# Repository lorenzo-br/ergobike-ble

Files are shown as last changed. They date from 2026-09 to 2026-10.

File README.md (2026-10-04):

# 🚴 ErgoBike BLE - Adaptador Bluetooth Smart para Bike Ergométrica

<p align="center">
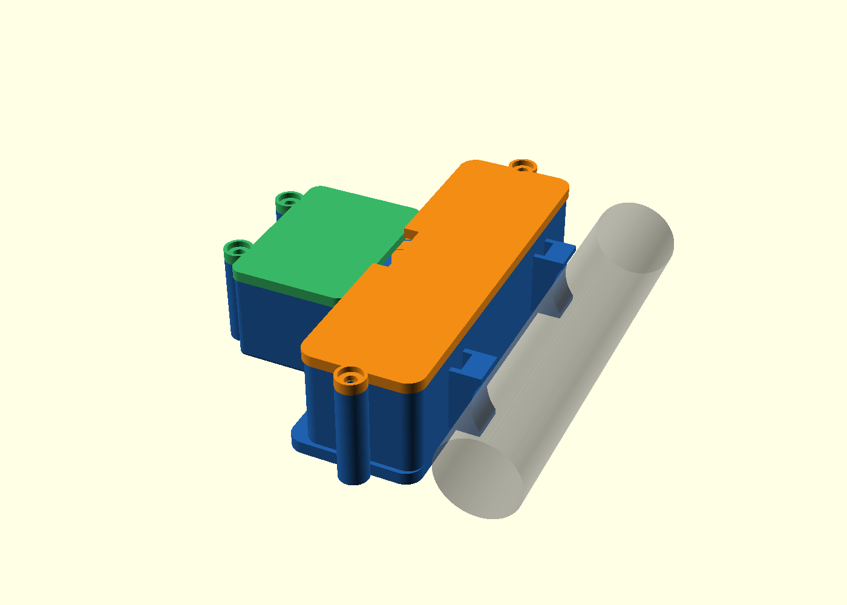
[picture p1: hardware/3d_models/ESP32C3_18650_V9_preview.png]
ErgoBike BLE 3D Enclosure
  
</p>

<p align="center">
  
  
  
  
  
</p>

---

Transforme sua bicicleta ergométrica convencional com medidor de pulso simples (cabo P1/P2) em um **Smart Indoor Trainer Bluetooth** completo e de alta precisão, compatível nativamente com o **CycleGo**, **Zwift**, **MyWhoosh**, **Kinomap**, **Wahoo Fitness**, **Rouvy**, **Strava** e outros aplicativos de treino indoor.

Desenvolvido para **ESP32-C3** (RISC-V) alimentado por uma bateria **18650**, com consumo ultra-baixo em repouso (**Deep Sleep < 15 µA**), despertar automático ao primeiro giro do pedal e um **Portal Wi-Fi de Auto-Calibração** sem necessidade de abrir a carenagem da bike.

---

## 🌟 Principais Recursos

- **Dual-Stack BLE Oficial (CSCS + FTMS + BAS):**
  - **CSCS (Cycling Speed and Cadence Service - `0x1816`):** Padrão universal para cadência e velocidade com base de tempo de 1/1024s, SC Control Point (`0x2A55`) e localização do sensor.
  - **FTMS (Fitness Machine Service - `0x1826`):** Padrão moderno de *Indoor Bike Data* (`0x2AD2`) com velocidade, cadência, potência estimada (Watts), Status (`0x2ADA`) e Control Point (`0x2AD9`).
  - **Battery Service (`0x180F`):** Monitoramento contínuo da porcentagem da célula 18650 diretamente no app.
- **Assistente de Auto-Calibração (10 Voltas no Pedal):**
  - Calibração guiada via navegador: dê 10 voltas no pedal e o sistema calcula a relação de polia da roda de inércia automaticamente.
- **Gestão Inteligente de Energia (Deep Sleep):**
  - Desliga automaticamente após 3 minutos de inatividade.
  - Desperta instantaneamente no primeiro pulso do ímã (GPIO 21 interrupt wake).
- **Portal Web Wi-Fi Responsivo + Atualização OTA:**
  - Dashboard ao vivo com velocímetro, cadência e nível de bateria.
  - Atualização de firmware sem fios (Over-The-Air) pelo celular ou notebook.
- **Enclosure 3D V9 Sob Medida:**
  - Compartimento dedicado para ESP32-C3 + suporte para bateria 18650 com tampas parafusadas e abraçadeira para tubo de 20 mm.

---

## 📱 Compatibilidade de Aplicativos

| Aplicativo | Protocolo BLE Utilizado | Métricas Suportadas |
| :--- | :--- | :--- |
| **CycleGo** | CSCS / FTMS | Cadência (RPM) e Velocidade (km/h) |
| **Zwift** | FTMS / CSCS | Cadência, Velocidade, Potência Estimada e Bateria |
| **MyWhoosh** | FTMS / CSCS | Cadência, Velocidade e Potência Estimada |
| **Kinomap** | FTMS / CSCS | Cadência, Velocidade e Potência Estimada |
| **Wahoo Fitness** | CSCS | Cadência, Velocidade e Bateria |
| **Rouvy** | CSCS | Cadência e Velocidade Virtual |
| **Strava** (Gravação) | CSCS | Cadência e Velocidade do Treino |
| **nRF Connect** | CSCS + FTMS + BAS + DIS | Diagnóstico completo de GATT |

---

## 🛠️ Esquema Elétrico e Conexões

### Opção A: Placa de Expansão ESP32-C3 SuperMini (AliExpress) — *Recomendado*

A placa de expansão para ESP32-C3 SuperMini simplifica a montagem física:
- **Porta de Bateria PH2.0 integrada:** basta plugar a bateria 3.7V (18650 ou LiPo com conector PH2.0).
- **Carregador de Bateria Onboard (LTC4054/LTH7R):** recarrega a bateria diretamente pela porta USB-C da placa com LED indicador de carga (Verde aceso = carregando, apagado = carregado/uso).
- **Barramentos G-V-S (Ground, VCC, Signal):** facilitam o encaixe com conectores fêmea dupont.

```
                  Placa de Expansão ESP32-C3 SuperMini
                  +-----------------------------------+
[ BATERIA 3.7V ]  | [ Conector PH2.0 "BAT" ]          |
Célula 18650 ---->| (Carregador Onboard + Regulador)  |
                  |                                   |
[ JACK P2 BIKE ]  | Barramento GPIO 21 (G - V - S)    |
Ponta (Sinal) ------------------------------------> (S - Amarelo) GPIO 21 (INPUT_PULLUP)
Malha (GND)   ------------------------------------> (G - Preto)   GND
                                                   [V - Vermelho] VAZIO (NÃO LIGAR)
                  |                                   |
[ BOTÃO BOOT ]    | Integrado no ESP32-C3 SuperMini   | (GPIO 9 - Segure 2s para Wi-Fi)
[ LED STATUS ]    | Integrado no ESP32-C3 SuperMini   | (GPIO 8 - Onboard Blue LED)
                  +-----------------------------------+

* Nota sobre Monitoramento de Bateria:
- A placa de expansão alimenta o ESP32-C3 via regulador 3.3V integrado.
- Modo Padrão Automático: Se não conectar divisor externo no GPIO 0, o firmware detecta
  alimentação direta via porta BAT e opera continuamente sem falso alerta de bateria fraca.
- (Opcional) Medição Precisa em Volts: Conecte um divisor 100k/100k entre o terminal positivo (BAT+)
  da bateria e o GND, com o ponto central ligado ao pino (S) do GPIO 0.
```

### Opção B: Montagem Avulsa / DevKitM-1 Tradicional

```
                       ESP32-C3
                   +---------------+
[ JACK P2 DA BIKE ]|               |
Ponta (Sinal) ---------------------| GPIO 21 (INPUT_PULLUP + WAKEUP)
Malha (GND)   -----+---------------| GND
                   |               |
[ BATERIA 18650 ]  |               |
Polo (+) ----------[ 100kΩ ]---+---| GPIO 0 (ADC1_CH0)
                               |   |
                           [ 100kΩ ]
                               |   |
Polo (-) ----------------------+---| GND
                                   |
[ BOTÃO SETUP ]--------------------| GPIO 9 (Nativo BOOT - Segure 2s para Wi-Fi)
[ LED STATUS ]---------------------| GPIO 8 (Ativo em nível LOW)
                   +---------------+
```

### Lista de Componentes Eletrônicos:
1. **Microcontrolador:** Placa ESP32-C3 SuperMini + **Placa de Expansão ESP32-C3 SuperMini** (AliExpress).
2. **Bateria:** Célula 18650 3.7V Li-ion (ou bateria LiPo) com conector JST PH 2.0mm.
3. **Conector do Sensor:** Conector Jack P2 (3.5 mm) ou P1 (2.5 mm) fêmea/macho.
4. **Resistor de Proteção:** 1x Resistor 1kΩ (ligado em série no pino de sinal para proteção ESD).
5. *(Opcional)* **2x Resistores 100kΩ:** apenas se desejar leitura analógica contínua da tensão da bateria no GPIO 0.

---

## 🖨️ Enclosure 3D (V9)

Os modelos 3D paramétricos estão disponíveis na pasta [`hardware/3d_models/`](hardware/3d_models/):

<p align="center">
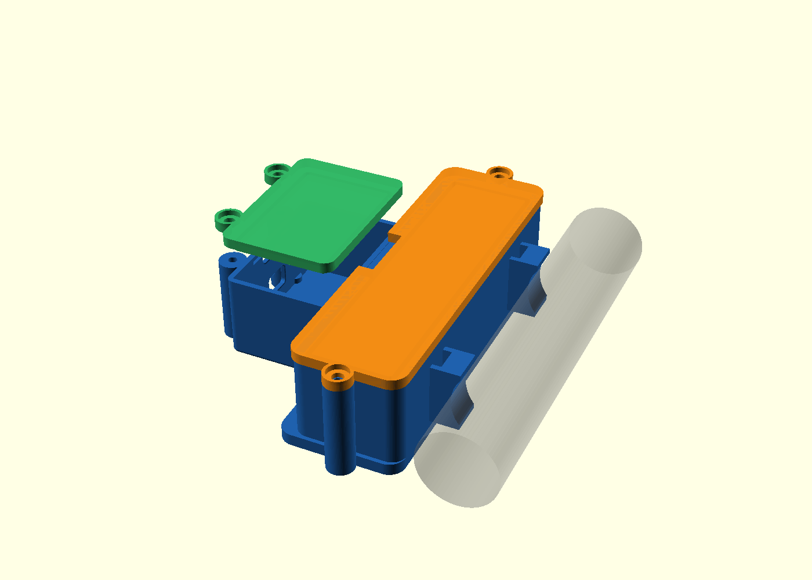
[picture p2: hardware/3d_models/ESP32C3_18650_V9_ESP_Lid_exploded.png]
Vista Explodida do Enclosure
  
</p>

* **Corpo Principal:** `ESP32C3_18650_Body_V9_ESP_ScrewLid.stl`
* **Tampa da Bateria:** `ESP32C3_18650_Battery_Lid_V9.stl`
* **Tampa do ESP32:** `ESP32C3_Lid_V9_2Screws.stl`
* **Parafusos recomendados:** 4x parafusos autoatarraxantes M2.5 x 8 mm para plástico.
* **Fixação na Bike:** Encaixe para tubo de 20 mm com ranhuras para abraçadeiras de nylon (*enforca-gato*).

> ⚠️ **Status de Compatibilidade Parcial & Via de Contribuição:**<br>
> O modelo 3D atual (V9) é funcional, porém possui **compatibilidade parcial**, pois foi modelado com base em um tubo de fixação específico (~20 mm) e dimensões de componentes particulares. Dependendo do diâmetro do tubo da sua ergométrica, do tipo de conector P2/P1 ou do holder de bateria utilizado, podem ser necessários ajustes.<br>
> **Melhorias e variantes 3D são uma das principais vias de contribuição para este projeto!** Se você desenvolver novos suportes, cases para outros diâmetros de quadro, presilhas ou modelos em STEP/OpenSCAD, envie seu Pull Request!

---

## 🚀 Compilação e Gravação

### Ambientes Disponíveis (PlatformIO)
* **`esp32-c3` (Padrão de Produção):** Perfil Dual completo com **CSCS** (`0x1816` + `0x2A55`), **FTMS** (`0x1826` com potência estimada, Status e Control Point) e **Battery Service** (`0x180F`).
* **`esp32-c3-ftms-only`:** Perfil isolado FTMS para diagnósticos específicos em simuladores que exigem exclusivamente FTMS.

### Usando PlatformIO (Linha de Comando ou VS Code)
1. Clone este repositório:
   ```bash
   git clone https://github.com/lorenzo-br/ergobike-ble.git
   cd ergobike-ble
   ```
2. Compile e grave o ambiente padrão:
   ```bash
   pio run -e esp32-c3 -t upload
   ```
3. (Opcional) Execute todos os testes unitários nativos de mesa:
   ```bash
   pio test -e native
   ```

### Usando Arduino IDE
1. Adicione a URL do ESP32 em *Arquivo > Preferências*:
   `https://espressif.github.io/arduino-esp32/package_esp32_index.json`
2. Instale as bibliotecas via Gerenciador de Bibliotecas:
   - `NimBLE-Arduino`
   - `ArduinoJson`
   - `ESPAsyncWebServer` e `AsyncTCP`
3. Selecione a placa **ESP32C3 Dev Module** e realize o upload.

---

## 📱 Guia de Uso e Calibração

### 1. Calibração Inicial sem Fio (Modo Wi-Fi)
1. Ligue o dispositivo segurando o **botão BOOT (GPIO 9)** por 2 a 3 segundos.
2. O LED de status começará a **piscar rapidamente**.
3. No smartphone ou computador, conecte na rede Wi-Fi:
   - **Nome da Rede (SSID):** `ErgoBike-Setup`
   - **Senha:** `12345678`
4. Abra o navegador em `http://192.168.4.1`.
5. Na seção **Assistente de Auto-Calibração**:
   - Clique em **"1. Iniciar Contagem"**.
   - Dê exatamente **10 voltas completas** no pedal da bike.
   - Clique em **"2. Concluir Calibração"**.
   - O sistema salvará a relação calculada diretamente na memória Flash (NVS)!
6. Clique em **"Reiniciar em Modo BLE"**.

---

### 2. Conexão no **CycleGo**
1. Abra o aplicativo **CycleGo** (iOS / Android).
2. Acesse a tela de conexão de sensores.
3. Conecte o sensor chamado **`ErgoBike-BLE`**.
4. Pronto! Ao pedalar, suas métricas de cadência e velocidade virtual responderão instantaneamente.

---

## 🧪 Testes Unitários de Algoritmo

O projeto inclui suíte de testes de mesa em C++17 para validação das fórmulas matemáticas, filtros de debounce e curva da bateria:

```bash
# Executar testes unitários nativos (MSVC / GCC / Clang)
cl /EHsc /std:c++17 /DNATIVE_TEST /Iinclude src\sensor_reader.cpp test\test_sensor_math.cpp /Fe:test_sensor.exe && test_sensor.exe
cl /EHsc /std:c++17 /DNATIVE_TEST /Iinclude src\battery_monitor.cpp test\test_battery_math.cpp /Fe:test_battery.exe && test_battery.exe
```

---

## 📁 Estrutura de Arquivos

```
ergobike_ble/
├── hardware/
│   └── 3d_models/           # Arquivos STL, OpenSCAD e imagens do Case V9
├── include/
│   ├── config.h             # Pinos, parâmetros e UUIDs dos serviços BLE
│   ├── sensor_reader.h      # Processamento de pulso, debounce e métricas
│   ├── ble_manager.h        # Servidor BLE (CSCS, FTMS, Battery Service)
│   ├── csc_control_point.h  # Protocolo e respostas do CSC Control Point (0x2A55)
│   ├── ftms_control_point.h # Protocolo e respostas do FTMS Control Point (0x2AD9)
│   ├── ftms_indoor_bike_data.h # Empacotamento FTMS e estimador de potência
│   ├── storage_manager.h    # Persistência de parâmetros e migração Flash NVS
│   ├── battery_monitor.h    # Leitura de ADC e curva percentual da 18650
│   ├── power_manager.h      # Inatividade e controle de Deep Sleep
│   ├── web_assets.h         # Single-Page Web App embarcada
│   └── web_portal.h         # Servidor Web, Captive DNS e OTA Updater
├── src/
│   ├── main.cpp             # Orquestrador e máquina de estados principal
│   ├── sensor_reader.cpp
│   ├── ble_manager.cpp
│   ├── storage_manager.cpp
│   ├── battery_monitor.cpp
│   ├── power_manager.cpp
│   └── web_portal.cpp
├── test/                    # Suíte completa de testes unitários nativos (7 casos)
│   ├── test_sensor_math.cpp
│   ├── test_battery_math.cpp
│   ├── test_ble_profile.cpp
│   ├── test_ftms_control_point.cpp
│   ├── test_ftms_indoor_bike_data.cpp
│   ├── test_csc_control_point.cpp
│   └── test_config_defaults.cpp
├── platformio.ini           # Ambientes esp32-c3, esp32-c3-ftms-only e native
├── min_spiffs.csv           # Tabela de partições (Flash OTA 4MB)
├── LICENSE                  # Licença MIT
└── README.md
```

---

## 🤝 Como Contribuir

Contribuições de toda a comunidade ciclista e maker são muito bem-vindas! Algumas formas diretas de colaborar:

1. **Modelagem 3D & Adaptações Mecânicas:**
   - Criar variantes do case para diferentes diâmetros de quadro de bicicleta (22 mm, 25 mm, tubos ovais, etc.).
   - Desenvolver suportes alternativos para outros tipos de baterias (14500, LiPo plana, holders com trava).
   - Disponibilizar arquivos em formatos universais (`STEP`, `F3D`, `FreeCAD`).
2. **Compatibilidade com Novos Aplicativos:**
   - Testar o sensor em outros apps de ciclismo indoor (GoldenCheetah, TrainerRoad, FulGaz, etc.) e reportar feedback nas *Issues*.
3. **Firmware & Recursos:**
   - Abrir *Pull Requests* com testes unitários adicionais, otimizações de consumo de energia ou refinamentos na estimativa de potência.

---

## 📄 Licença

Este projeto é disponibilizado sob a licença **MIT**. Consulte o arquivo [LICENSE](LICENSE) para mais detalhes. Sinta-se livre para usar, modificar e compartilhar.

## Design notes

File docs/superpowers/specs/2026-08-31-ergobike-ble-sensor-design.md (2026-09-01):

# Especificação Técnica de Design: Adaptador BLE para Ergométrica com ESP32-C3

**Data:** 31 de Agosto de 2026  
**Status:** Aprovado para Implementação  
**Autor:** Antigravity / OpenCode Pair Programming  
**Hardware Alvo:** ESP32-C3 + Célula 18650 + Conector Jack P1/P2 + Enclosure V9

---

## 1. Visão Geral e Objetivos

O objetivo deste projeto é transformar uma bicicleta ergométrica convencional sem eletrônica inteligente em um *Smart Indoor Trainer* via **Bluetooth Low Energy (BLE)** de alta precisão e baixo consumo de energia.

O sistema intercepta os pulsos gerados pelo sensor magnético de rotação (reed switch / hall) através do conector P1/P2 (3.5mm/2.5mm mono), processa os pulsos via interrupções de hardware com debounce digital e filtro de média móvel no microcontrolador ESP32-C3, e transmite dados em tempo real para aplicativos de treino indoor (como **CycleGo**, Zwift, Kinomap, Rouvy, Wahoo, Strava).

### Principais Diferenciais:
1. **Dual BLE Stack (CSCS + FTMS):** Suporte nativo ao serviço clássico *Cycling Speed and Cadence* (UUID `0x1816`) e ao padrão moderno *Fitness Machine Service* (UUID `0x1826` - Indoor Bike Data), além do *Battery Service* (UUID `0x180F`).
2. **Portal Web Wi-Fi de Calibração e Teste:** Interface responsiva hospedada no próprio ESP32 para calibrar a relação de transmissão (assistente de 10 voltas de pedal), diâmetro virtual da roda, tempos de debounce e atualização de firmware via OTA sem necessidade de cabos.
3. **Gestão Inteligente de Energia com Deep Sleep:** Consumo ultra-baixo (< 15 µA) em repouso com desligamento automático após 3 minutos de inatividade e despertar instantâneo ao primeiro giro da roda/pedal.
4. **Proteção Eletrônica e Monitoramento da Bateria 18650:** Divisor resistivo com curva de calibração para leitura precisa de tensão e proteção contra descarga profunda da célula 18650.

---

## 2. Arquitetura de Hardware e Conexões

### 2.1 Pinout do ESP32-C3

| Função | Pino ESP32-C3 | Tipo | Descrição / Circuito |
| :--- | :--- | :--- | :--- |
| **Entrada Sensor P2** | `GPIO 3` | Digital Input (Interrupt + Deep Sleep Wakeup) | Conectado à ponta do conector P2 com resistor em série de 1kΩ e Pull-Up interno ativado. Nível LOW quando ímã aproxima. |
| **GND Sensor P2** | `GND` | Terra comum | Conectado à malha do conector P2. |
| **Leitura Bateria 18650** | `GPIO 0` | ADC1_CH0 | Divisor de tensão resistivo $100\text{k}\Omega / 100\text{k}\Omega$ ligado diretamente ao polo positivo da célula 18650. |
| **Botão de Setup / Wi-Fi** | `GPIO 9` | Digital Input (BOOT) | Botão nativo BOOT. Pressionado por 3s no boot inicia o Portal Wi-Fi de Configuração. |
| **LED de Status** | `GPIO 8` | Digital Output | LED onboard / externo indicando BLE anunciando, conectado, pulso de pedal ou modo Wi-Fi. |

### 2.2 Esquema Elétrico de Proteção e Interface

```
                       ESP32-C3
                   +---------------+
[ JACK P2 ]        |               |
Ponta (Sinal) -----[ 1kΩ ]---------| GPIO 3 (PULL-UP)
                   |               |
Malha (GND)   -----+---------------| GND
                   |               |
[ BATERIA 18650 ]  |               |
Polo (+) ----------[ 100kΩ ]---+---| GPIO 0 (ADC)
                               |   |
                           [ 100kΩ ]
                               |   |
Polo (-) ----------------------+---| GND
                                   |
[ BOTÃO BOOT ]---------------------| GPIO 9 (PULL-UP)
[ LED STATUS ]---------------------| GPIO 8
                   +---------------+
```

---

## 3. Arquitetura do Firmware

O firmware é desenvolvido em C++ modular sob o framework Arduino / ESP-IDF (PlatformIO).

### 3.1 Estrutura de Diretórios

```
ergobike_ble/
├── include/
│   ├── config.h              # Definições de pinos, padrões de fábrica e constantes de tempo
│   ├── sensor_reader.h       # ISR do sensor, debounce por software, cálculo de RPM e velocidade
│   ├── ble_manager.h         # Servidor BLE, serviços CSCS (0x1816), FTMS (0x1826), Battery (0x180F)
│   ├── storage_manager.h     # Persistência em NVS Flash (Preferences)
│   ├── battery_monitor.h     # Leitura do ADC, conversão para mV e curva percentual da 18650
│   ├── power_manager.h       # Controle de inatividade, light sleep e deep sleep com wakeup
│   └── web_portal.h          # Ponto de acesso Wi-Fi, Servidor Web assíncrono, WebSockets e OTA
├── src/
│   ├── main.cpp              # Inicialização, orquestração e loop principal
│   ├── sensor_reader.cpp
│   ├── ble_manager.cpp
│   ├── storage_manager.cpp
│   ├── battery_monitor.cpp
│   ├── power_manager.cpp
│   └── web_portal.cpp
├── platformio.ini             # Configuração de build, flags de compilação e bibliotecas
└── README.md
```

---

## 4. Algoritmos e Detalhes dos Módulos

### 4.1 SensorReader (Detecção e Métricas)
- **Interrupção:** `attachInterrupt(digitalPinToInterrupt(PIN_SENSOR), isr_sensor_trigger, FALLING)`.
- **Filtro de Debounce Dinâmico:** Intervalos inferiores ao tempo de debounce configurado (padrão 15 ms) são descartados na ISR.
- **Base de Tempo:** Medição do delta de tempo ($\Delta t = t_{\text{atual}} - t_{\text{anterior}}$) em microssegundos com `esp_timer_get_time()`.
- **Filtro de Suavização:** *Moving Average* com buffer circular dos últimos 4 pulsos para compensar irregularidades na inércia mecânica.
- **Relação de Transmissão e Conversões:**
  - $\text{RPM}_{\text{pedal}} = \frac{60 \times 10^6}{\Delta t_{\mu s} \times \text{gear\_ratio}}$
  - $\text{Velocidade}_{\text{km/h}} = \left(\frac{\text{wheel\_circ}_{\text{mm}} \times 3600}{\Delta t_{\mu s} \times \text{gear\_ratio}}\right)$
- **Timeout de Parada Imediata:** Se passar mais de 2,0 segundos sem pulso, a velocidade e o RPM são zerados instantaneamente.

### 4.2 BLEManager (Protocolos de Transmissão)
- **Serviço CSCS (0x1816):**
  - Característica `0x2A5B` (*CSC Measurement* - Notify):
    - Byte 0: Flags (`0x03` = Wheel Revolutions Present + Crank Revolutions Present).
    - Bytes 1..4: `Cumulative Wheel Revolutions` (uint32).
    - Bytes 5..6: `Last Wheel Event Time` (uint16, resolução $1/1024\text{ s}$).
    - Bytes 7..8: `Cumulative Crank Revolutions` (uint16).
    - Bytes 9..10: `Last Crank Event Time` (uint16, resolução $1/1024\text{ s}$).
  - Característica `0x2A5C` (*CSC Feature* - Read): `0x03`.
  - Característica `0x2A5D` (*Sensor Location* - Read): `0x0C` (Rear Dropout / Trainer).
- **Serviço FTMS (0x1826):**
  - Característica `0x2AD2` (*Indoor Bike Data* - Notify):
    - Flags: Instantaneous Speed present, Instantaneous Cadence present.
    - Velocidade instantânea em unidades de $0.01\text{ km/h}$.
    - Cadência instantânea em unidades de $0.5\text{ RPM}$.
- **Serviço de Bateria (0x180F):**
  - Característica `0x2A19` (*Battery Level* - Read/Notify): Percentual de 0 a 100%.

### 4.3 WebPortal e Auto-Calibração
- **Rede Wi-Fi:** AP com SSID `ErgoBike-BLE-Setup` e IP `192.168.4.1`.
- **Assistente de Calibração Guiada:**
  - O usuário aciona "Iniciar Calibração" na página.
  - O usuário pedala exatamente 10 voltas completas.
  - O ESP32 conta os pulsos $N_{\text{pulsos}}$ recebidos da roda de inércia.
  - A relação é calculada automaticamente: $\text{gear\_ratio} = \frac{N_{\text{pulsos}}}{10.0}$.
- **Live WebSocket Dashboard:** Exibe RPM, Velocidade em km/h e pulsos detectados em tempo real na tela do smartphone.
- **Painel de Configuração NVS:** Ajuste de debounce, circunferência, timeout de sleep e calibração de voltagem.
- **Atualização OTA:** Endpoint `/update` para upload de novo binário de firmware pelo navegador.

### 4.4 PowerManager (Deep Sleep)
- **Critério de Inatividade:** Sem pulso no sensor e sem cliente BLE conectado por 3 minutos.
- **Procedimento de Suspensão:**
  1. Salva estado acumulado em Flash NVS.
  2. Desativa Wi-Fi e rádio BLE.
  3. Configura `gpio_wakeup_enable(GPIO_NUM_3, GPIO_INTR_LOW_LEVEL)`.
  4. Ativa `esp_deep_sleep_enable_gpio_wakeup((1ULL << GPIO_NUM_3), ESP_GPIO_WAKEUP_GPIO_LOW)`.
  5. Entra em `esp_deep_sleep_start()`.
- **Despertar:** Ao primeiro giro do volante, o ímã puxa GPIO 3 para LOW, reiniciando o ESP32 imediatamente.

---

## 5. Estratégia de Teste e Validação

1. **Testes Unitários e de Algoritmo:**
   - Validação da máquina de estados do debounce e ring buffer de média móvel com simulação de jitter e repique mecânico.
   - Validação da formatação dos bytes CSCS ($1/1024\text{ s}$ wrap-around em 64 segundos).
2. **Testes de Integração BLE:**
   - Conexão e leitura de dados no app **CycleGo** (iOS / Android).
   - Teste de compatibilidade em **Zwift** e **nRF Connect** para validação dos descritores BLE e taxas de notificação.
3. **Teste de Calibração e Persistência NVS:**
   - Verificação do cálculo do assistente de 10 voltas e persistência após reinicialização.
4. **Teste de Consumo e Transição de Sono:**
   - Medição do consumo em repouso e validação do acionamento no primeiro pulso.

---

## 6. Aprovação

Este documento estabelece todos os requisitos, arquiteturas e especificações necessárias para a implementação completa do firmware e ferramentas do projeto.

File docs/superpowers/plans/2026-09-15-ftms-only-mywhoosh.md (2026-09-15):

# MyWhoosh FTMS-Only Compatibility Test Implementation Plan

> **For agentic workers:** REQUIRED SUB-SKILL: Use superpowers:subagent-driven-development (recommended) or superpowers:executing-plans to implement this plan task-by-task. Steps use checkbox (`- [ ]`) syntax for tracking.

**Goal:** Provide a reversible ESP32-C3 firmware environment that exposes only FTMS for MyWhoosh compatibility testing while preserving the existing dual CSC + FTMS firmware.

**Architecture:** Keep the current dual-stack behavior as the default. Add a compile-time `ERGOBIKE_FTMS_ONLY` profile that conditionally omits the CSC service, CSC notifications, and CSC advertising UUID; FTMS and Battery remain unchanged. Add a dedicated PlatformIO environment so the test image can be flashed without changing the default production profile.

**Tech Stack:** C++17, Arduino ESP32-C3, NimBLE-Arduino, PlatformIO, native C++ tests.

**Spec:** `docs/superpowers/specs/2026-08-31-ergobike-ble-sensor-design.md`

## Global Constraints

- Target board: `esp32-c3-devkitm-1`.
- Sensor input: `GPIO21`.
- FTMS service: `0x1826`, Indoor Bike Data characteristic `0x2AD2`.
- FTMS instantaneous speed unit: `0.01 km/h`.
- FTMS instantaneous cadence unit: `0.5 RPM`.
- The default `esp32-c3` environment remains dual CSC + FTMS.
- The FTMS-only image is a reversible compatibility test; restore the default environment if MyWhoosh does not accept it.
- No USB and bike connection is required at the same time: flash with the sensor disconnected, then test from the battery.

---

### Task 1: Add a tested FTMS-only profile switch

**Files:**
- Modify: `include/config.h:25-35`
- Modify: `include/ble_manager.h:9-32`
- Create: `test/test_ble_profile.cpp`

**Interfaces:**
- Consumes: optional compiler macro `ERGOBIKE_FTMS_ONLY`.
- Produces: `BLEManager::cscServiceEnabled()` as a compile-time profile query for tests and build-time behavior.

- [ ] **Step 1: Write the failing test**

Create `test/test_ble_profile.cpp`:

```cpp
#include <cassert>
#include "ble_manager.h"

int main() {
    assert(BLEManager::cscServiceEnabled() == false);
    return 0;
}
```

- [ ] **Step 2: Run the test to verify it fails**

Run from `H:\ergobike-ble`:

```powershell
g++ -std=c++17 -DNATIVE_TEST -DERGOBIKE_FTMS_ONLY=1 -Iinclude test/test_ble_profile.cpp -o test_ble_profile.exe
```

Expected: compilation fails because `BLEManager::cscServiceEnabled()` does not exist yet.

- [ ] **Step 3: Add the profile macro and query**

Add to `include/config.h`:

```cpp
#ifndef ERGOBIKE_FTMS_ONLY
#define ERGOBIKE_FTMS_ONLY 0
#endif
```

Add to `BLEManager` in `include/ble_manager.h`:

```cpp
static constexpr bool cscServiceEnabled() {
    return ERGOBIKE_FTMS_ONLY == 0;
}
```

- [ ] **Step 4: Run the test to verify it passes**

Run:

```powershell
g++ -std=c++17 -DNATIVE_TEST -DERGOBIKE_FTMS_ONLY=1 -Iinclude test/test_ble_profile.cpp -o test_ble_profile.exe
test_ble_profile.exe
```

Expected: exit code `0`.

- [ ] **Step 5: Remove the generated test executable**

```powershell
Remove-Item -LiteralPath test_ble_profile.exe -ErrorAction SilentlyContinue
```

- [ ] **Step 6: Commit the tested profile switch**

```powershell
git add include/config.h include/ble_manager.h test/test_ble_profile.cpp
git commit -m "test: add FTMS-only BLE profile switch"
```

### Task 2: Implement conditional BLE service exposure

**Files:**
- Modify: `src/ble_manager.cpp:66-90`
- Modify: `src/ble_manager.cpp:153-160`
- Modify: `src/ble_manager.cpp:166-200`
- Modify: `src/ble_manager.cpp:238-247`

**Interfaces:**
- Consumes: `ERGOBIKE_FTMS_ONLY` and `BLEManager::cscServiceEnabled()` from Task 1.
- Produces: FTMS-only builds with service UUID `0x1826`, Indoor Bike Data `0x2AD2`, and Battery service `0x180F`; dual builds retain CSC behavior.

- [ ] **Step 1: Write the failing build check**

Run the FTMS-only environment before conditional guards exist:

```powershell
pio run -e esp32-c3-ftms-only
```

Expected: fail because the environment does not exist yet.

- [ ] **Step 2: Guard CSC creation and advertising**

Wrap the CSC service creation, feature, sensor location, and `pCscService->start()` block in `begin()` with:

```cpp
#if !ERGOBIKE_FTMS_ONLY
    // existing CSC service setup
#endif
```

Wrap the CSC advertising line similarly:

```cpp
#if !ERGOBIKE_FTMS_ONLY
    pAdvertising->addServiceUUID(UUID_SERVICE_CSC);
#endif
```

- [ ] **Step 3: Guard CSC notification paths**

Wrap the body of `notifyCSC()` and its call in `update()` with `#if !ERGOBIKE_FTMS_ONLY`. FTMS notifications must continue to run every 500 ms in both profiles.

- [ ] **Step 4: Add the dedicated PlatformIO environment**

Append to `platformio.ini`:

```ini
[env:esp32-c3-ftms-only]
extends = env:esp32-c3
build_flags =
    ${env:esp32-c3.build_flags}
    -D ERGOBIKE_FTMS_ONLY=1
```

- [ ] **Step 5: Run the FTMS-only build**

```powershell
pio run -e esp32-c3-ftms-only
```

Expected: successful ESP32-C3 build with no CSC compilation errors.

- [ ] **Step 6: Run the default dual-stack build**

```powershell
pio run -e esp32-c3
```

Expected: successful build; default profile remains unchanged.

- [ ] **Step 7: Run all native tests**

```powershell
pio test -e native
```

Expected: existing sensor and battery suites pass.

- [ ] **Step 8: Commit the conditional BLE implementation**

```powershell
git add src/ble_manager.cpp platformio.ini
git commit -m "feat: add FTMS-only MyWhoosh test environment"
```

### Task 3: Flash and validate the FTMS-only image

**Files:**
- Build artifact: `.pio/build/esp32-c3-ftms-only/firmware.bin`
- No source changes.

**Interfaces:**
- Consumes: `esp32-c3-ftms-only` environment from Task 2.
- Produces: flashed image that advertises FTMS and Battery but not CSC.

- [ ] **Step 1: Disconnect the sensor cable and keep USB connected**

Leave the bike sensor/Y cable disconnected during flashing so the ESP32-C3 can be powered and monitored through USB.

- [ ] **Step 2: Flash FTMS-only**

```powershell
pio run -e esp32-c3-ftms-only -t upload --upload-port COM5
```

Expected: `Hash of data verified` and `SUCCESS`.

- [ ] **Step 3: Reconnect sensor and battery after flashing**

Disconnect USB, reconnect the LM393 output to `GPIO21`, connect the battery, and do not hold BOOT.

- [ ] **Step 4: Verify with nRF Connect**

Expected:
- `Fitness Machine (0x1826)` is present.
- `Indoor Bike Data (0x2AD2)` has notifications.
- Instantaneous Speed and Instantaneous Cadence change while pedaling.
- CSC service `0x1816` is absent.

- [ ] **Step 5: Verify with MyWhoosh**

Close nRF Connect fully, connect `ErgoBike-BLE` in MyWhoosh as the indoor bike/smart trainer, and pedal. Record whether RPM changes and record the displayed speed in both `km/h` and `m/s`.

- [ ] **Step 6: Decide compatibility result**

If RPM works, keep FTMS-only for MyWhoosh and calibrate speed from the FTMS value. If RPM remains zero, restore the default dual-stack image and investigate MyWhoosh's CSC cadence slot or app limitations.

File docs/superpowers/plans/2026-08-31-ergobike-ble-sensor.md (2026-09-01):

# ErgoBike BLE Sensor Implementation Plan

> **For agentic workers:** REQUIRED SUB-SKILL: Use superpowers:subagent-driven-development (recommended) or superpowers:executing-plans to implement this plan task-by-task. Steps use checkbox (`- [ ]`) syntax for tracking.

**Goal:** Build a complete, production-ready, ultra-low power ESP32-C3 firmware that converts stationary bike P1/P2 pulse signals into standard BLE Cycling Speed and Cadence (CSCS) and Fitness Machine Service (FTMS) data with a responsive Wi-Fi calibration web portal, battery monitoring, and deep sleep.

**Architecture:** Modular C++ firmware structured around an ISR sensor processor with software debouncing and ring-buffer moving average, dual-stack BLE broadcasting (CSCS 0x1816 + FTMS 0x1826 + Battery 0x180F), NVS persistent configuration storage, an asynchronous captive Wi-Fi portal with a live WebSocket calibration wizard and OTA updater, and an ultra-low power manager with GPIO-wake deep sleep.

**Tech Stack:** C++17, ESP32-C3 Arduino Framework / ESP-IDF, NimBLE-Arduino (or standard ESP32 BLE), ESPAsyncWebServer / WebSockets, Preferences (NVS), PlatformIO build configuration, and native desktop C++ unit testing for core math and signal algorithms.

## Global Constraints

- Target Microcontroller: ESP32-C3 (RISC-V single-core, 4MB Flash).
- Enclosure compatibility: V9 3D enclosure (ESP32 compartment + 18650 battery holder).
- Sensor Pin: `GPIO 3` (Input with internal pull-up and interrupt, wake-capable).
- Battery ADC Pin: `GPIO 0` (ADC1 Channel 0 with 100k/100k voltage divider).
- Setup Button: `GPIO 9` (Native BOOT pin, active LOW).
- Status LED: `GPIO 8` (Active LOW / HIGH configurable).
- BLE Services: CSCS (`0x1816`), FTMS (`0x1826`), Battery (`0x180F`), Device Info (`0x180A`).
- Target Apps: CycleGo, Zwift, Rouvy, Kinomap, Strava, Wahoo.

---

## File Structure Map

- `platformio.ini`: PlatformIO project configuration for ESP32-C3 and native unit tests.
- `include/config.h`: Pin definitions, default constants, BLE UUIDs, and system structures.
- `include/sensor_reader.h` & `src/sensor_reader.cpp`: Hardware interrupt handler, debounce filter, circular buffer, speed/cadence calculations.
- `include/storage_manager.h` & `src/storage_manager.cpp`: NVS flash storage for settings and calibration parameters.
- `include/battery_monitor.h` & `src/battery_monitor.cpp`: ADC readings, voltage calibration, and battery percentage curve.
- `include/ble_manager.h` & `src/ble_manager.cpp`: BLE GATT server, CSCS characteristic formatter (1/1024s timebase), FTMS characteristic formatter, and battery notification.
- `include/power_manager.h` & `src/power_manager.cpp`: Inactivity detection, timer reset, light sleep, and GPIO3 deep sleep wakeup.
- `include/web_portal.h` & `src/web_portal.cpp`: Wi-Fi AP server, live dashboard HTML/JS, 10-pedal calibration wizard, settings REST API, and OTA firmware updater.
- `src/main.cpp`: Main orchestrator, setup boot mode detection (Wi-Fi Config vs BLE Trainer), and main execution loop.
- `test/test_sensor_math.cpp`: Desktop unit tests for debounce, moving average, cadence/speed calculation, and 1/1024s timer rollover.
- `test/test_battery_math.cpp`: Desktop unit tests for ADC voltage divider calculations and battery percentage mapping.

---

### Task 1: Project Environment & PlatformIO Setup

**Files:**
- Create: `platformio.ini`
- Create: `include/config.h`
- Create: `.gitignore`

**Interfaces:**
- Produces: Base configuration types (`BikeConfig`), pin definitions (`PIN_SENSOR`, `PIN_BATTERY_ADC`, `PIN_LED_STATUS`, `PIN_BTN_SETUP`), and UUID definitions (`UUID_SERVICE_CSC`, `UUID_CHAR_CSC_MEAS`, etc.).

- [ ] **Step 1: Create `.gitignore`**
  Add standard PlatformIO, build, and editor ignore entries.

- [ ] **Step 2: Create `platformio.ini`**
  Configure `esp32-c3-devkitm-1` environment with appropriate board flags, upload speed, partitions, and dependencies (`ESP Async WebServer`, `AsyncTCP`, etc.) plus a `native` environment for running unit tests on host PC.

- [ ] **Step 3: Create `include/config.h`**
  Define all pin mappings, BLE UUID constants, default calibration numbers (e.g. `DEFAULT_WHEEL_CIRC_MM = 2096`, `DEFAULT_GEAR_RATIO = 4.5f`, `DEFAULT_DEBOUNCE_MS = 15`), and configuration struct.

- [ ] **Step 4: Verify build configuration syntax**
  Check that configuration headers and platformio setup are valid.

- [ ] **Step 5: Commit**
  `git add platformio.ini include/config.h .gitignore && git commit -m "chore: setup platformio config and project headers"`

---

### Task 2: Core Algorithm Unit Tests & SensorReader Engine

**Files:**
- Create: `include/sensor_reader.h`
- Create: `src/sensor_reader.cpp`
- Create: `test/test_sensor_math.cpp`

**Interfaces:**
- Consumes: `include/config.h`
- Produces: `class SensorReader` with methods:
  - `void begin()`
  - `void handlePulse(uint64_t timestamp_us)`
  - `void update()`
  - `float getCadenceRpm() const`
  - `float getSpeedKmh() const`
  - `uint32_t getCumulativeWheelRevs() const`
  - `uint16_t getLastWheelEventTime1024() const`
  - `uint16_t getCumulativeCrankRevs() const`
  - `uint16_t getLastCrankEventTime1024() const`
  - `void startCalibration()`
  - `float finishCalibration(uint16_t pedal_turns)`
  - `bool isCalibrating() const`
  - `uint32_t getCalibrationPulseCount() const`

- [ ] **Step 1: Write desktop test file for sensor math**
  Write tests in `test/test_sensor_math.cpp` verifying:
  - Debounce filtering (< `debounce_ms` ignored).
  - Accurate RPM & Speed calculation given $\Delta t$ and gear ratio.
  - Zero timeout (stops cadence/speed after 2 seconds of no pulses).
  - Calculation of 10-turn calibration ratio.
  - $1/1024\text{ s}$ resolution timebase and rollover math.

- [ ] **Step 2: Run test to verify it fails (TDD)**
  Execute native test runner (via C++ / g++ / test script) and verify failure before implementation.

- [ ] **Step 3: Implement `include/sensor_reader.h` and `src/sensor_reader.cpp`**
  Implement ISR pulse handling, rolling average buffer, and timeout zeroing logic.

- [ ] **Step 4: Run test to verify it passes**
  Execute native test runner and confirm 100% pass rate.

- [ ] **Step 5: Commit**
  `git add include/sensor_reader.h src/sensor_reader.cpp test/test_sensor_math.cpp && git commit -m "feat: implement sensor reader engine and algorithm unit tests"`

---

### Task 3: Battery Monitoring Engine & Unit Tests

**Files:**
- Create: `include/battery_monitor.h`
- Create: `src/battery_monitor.cpp`
- Create: `test/test_battery_math.cpp`

**Interfaces:**
- Consumes: `include/config.h`
- Produces: `class BatteryMonitor` with methods:
  - `void begin()`
  - `void update()`
  - `float getVoltage()`
  - `uint8_t getPercentage()`
  - `bool isCritical()`

- [ ] **Step 1: Write test for battery voltage and percentage mapping**
  Create `test/test_battery_math.cpp` validating Li-ion discharge curve interpolation:
  - $\ge 4.20\text{V} \rightarrow 100\%$
  - $3.85\text{V} \rightarrow \approx 60\%$
  - $3.70\text{V} \rightarrow \approx 30\%$
  - $3.20\text{V} \rightarrow 0\%$
  - $< 3.00\text{V} \rightarrow \text{critical alert}$.

- [ ] **Step 2: Run test to verify failure**

- [ ] **Step 3: Implement `include/battery_monitor.h` and `src/battery_monitor.cpp`**
  Implement ADC reading with multi-sampling (smoothing) and calibration divider ratio.

- [ ] **Step 4: Run test to verify pass**

- [ ] **Step 5: Commit**
  `git add include/battery_monitor.h src/battery_monitor.cpp test/test_battery_math.cpp && git commit -m "feat: implement battery monitor and discharge curve tests"`

---

### Task 4: NVS Storage Management

**Files:**
- Create: `include/storage_manager.h`
- Create: `src/storage_manager.cpp`

**Interfaces:**
- Consumes: `include/config.h` (`struct BikeConfig`)
- Produces: `class StorageManager` with methods:
  - `bool begin()`
  - `BikeConfig getConfig()`
  - `void saveConfig(const BikeConfig& cfg)`
  - `void resetDefaults()`

- [ ] **Step 1: Define `StorageManager` header and serialization layout**
- [ ] **Step 2: Implement Preferences / NVS storage read/write in `src/storage_manager.cpp`**
- [ ] **Step 3: Verify fallback to defaults when NVS is empty or uninitialized**
- [ ] **Step 4: Commit**
  `git add include/storage_manager.h src/storage_manager.cpp && git commit -m "feat: implement nvs storage manager for user preferences"`

---

### Task 5: BLE Server & GATT Services (CSCS + FTMS + Battery)

**Files:**
- Create: `include/ble_manager.h`
- Create: `src/ble_manager.cpp`

**Interfaces:**
- Consumes: `SensorReader`, `BatteryMonitor`, `config.h`
- Produces: `class BLEManager` with methods:
  - `void begin(const char* deviceName)`
  - `void update(const SensorReader& sensor, const BatteryMonitor& battery)`
  - `bool isConnected() const`
  - `void stop()`

- [ ] **Step 1: Define GATT Services and Characteristics structures**
  - Cycling Speed and Cadence Service (`0x1816`) with `0x2A5B` (Measurement), `0x2A5C` (Feature), `0x2A5D` (Location).
  - Fitness Machine Service (`0x1826`) with `0x2AD2` (Indoor Bike Data), `0x2ACC` (Feature).
  - Battery Service (`0x180F`) with `0x2A19` (Battery Level).
  - Device Information (`0x180A`).
- [ ] **Step 2: Implement BLE packet encoder conforming to Bluetooth SIG specifications**
  Correct little-endian byte ordering, 1/1024s timebase formatting, speed in 0.01 km/h and cadence in 0.5 RPM.
- [ ] **Step 3: Implement connection callbacks and advertising auto-restart**
- [ ] **Step 4: Commit**
  `git add include/ble_manager.h src/ble_manager.cpp && git commit -m "feat: implement dual ble stack cscs ftms and battery service"`

---

### Task 6: Power Management & Deep Sleep Controller

**Files:**
- Create: `include/power_manager.h`
- Create: `src/power_manager.cpp`

**Interfaces:**
- Consumes: `config.h`, `SensorReader`, `BLEManager`
- Produces: `class PowerManager` with methods:
  - `void begin()`
  - `void resetInactivityTimer()`
  - `void update(bool isPedaling, bool isBleConnected)`
  - `void enterDeepSleep()`
  - `uint32_t getSecondsUntilSleep() const`

- [ ] **Step 1: Implement inactivity timer calculation**
- [ ] **Step 2: Configure ESP32-C3 GPIO3 interrupt wake-up (`esp_deep_sleep_enable_gpio_wakeup`)**
- [ ] **Step 3: Implement clean pre-sleep shutdown (NVS flush, radio down)**
- [ ] **Step 4: Commit**
  `git add include/power_manager.h src/power_manager.cpp && git commit -m "feat: implement power manager with gpio wake deep sleep"`

---

### Task 7: Wi-Fi Setup Portal, Live WebSocket Dashboard, Calibration Wizard & OTA

**Files:**
- Create: `include/web_portal.h`
- Create: `src/web_portal.cpp`
- Create: `include/web_assets.h` (Embedded HTML5 / CSS3 / JavaScript single-page application)

**Interfaces:**
- Consumes: `SensorReader`, `BatteryMonitor`, `StorageManager`, `config.h`
- Produces: `class WebPortal` with methods:
  - `void begin(StorageManager* storage, SensorReader* sensor, BatteryMonitor* battery)`
  - `void update()`
  - `void stop()`

- [ ] **Step 1: Build modern, responsive single-page Web App (`web_assets.h`)**
  - **Live Dashboard:** Live RPM gauge, speed gauge, total pulses.
  - **10-Pedal Calibration Wizard:** Step-by-step interactive screen calculating gear ratio automatically.
  - **Settings Panel:** Wheel circumference, debounce time, deep sleep timer, battery voltage calibration.
  - **OTA Firmware Upload:** Form to flash `.bin` directly over Wi-Fi.
- [ ] **Step 2: Implement Async WebServer endpoints and WebSocket broadcaster**
  - `GET /`: Serves dashboard/config UI.
  - `GET /api/status`: JSON with live RPM, speed, battery, pulses, and config.
  - `POST /api/save`: Updates NVS settings.
  - `POST /api/calibrate/start` & `POST /api/calibrate/finish`: Runs wizard calculation.
  - `POST /update`: Handles multipart firmware upload.
- [ ] **Step 3: Implement DNS captive portal (redirects any URL to setup page)**
- [ ] **Step 4: Commit**
  `git add include/web_portal.h src/web_portal.cpp include/web_assets.h && git commit -m "feat: implement wifi setup portal live dashboard calibration wizard and ota"`

---

### Task 8: Main Application Orchestrator & Boot Logic

**Files:**
- Modify: `src/main.cpp`
- Create/Update: `README.md` (Complete wiring diagram, flashing instructions, calibration guide)

**Interfaces:**
- Orchestrates: All modules (`SensorReader`, `BLEManager`, `BatteryMonitor`, `StorageManager`, `PowerManager`, `WebPortal`).

- [ ] **Step 1: Implement `src/main.cpp`**
  - Boot mode detection: check if BOOT button is held $\ge 2\text{s}$ or if wake from deep sleep was requested.
  - If Config Mode: Start Wi-Fi AP + WebPortal, flash LED rapidly.
  - If Normal Mode: Start BLE Advertising + SensorReader + BatteryMonitor + PowerManager, blink LED with heartbeat.
- [ ] **Step 2: Run end-to-end unit tests and verification checks**
- [ ] **Step 3: Document hardware wiring, 3D enclosure assembly, and CycleGo app pairing in `README.md`**
- [ ] **Step 4: Commit**
  `git add src/main.cpp README.md && git commit -m "feat: integrate main orchestrator and documentation"`

---

## Plan Verification & Execution Strategy

1. **Host-based TDD:** Run native algorithmic tests on workstation before flashing.
2. **Deterministic Calibration:** Validate the 10-turn math against known flywheel ratios.
3. **App Verification:** Verify CSCS & FTMS packet integrity and compatibility with CycleGo and Zwift.

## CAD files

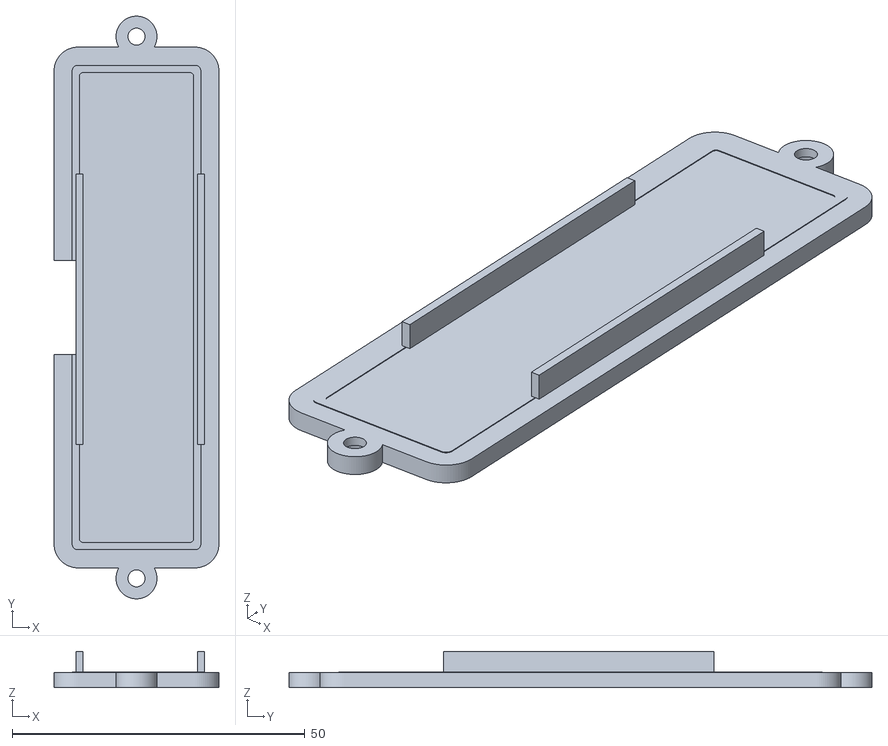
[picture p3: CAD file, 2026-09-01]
hardware/3d_models/ESP32C3_18650_Battery_Lid_V9-split-2-split-1-split-2.stl
28.2 x 99.6 x 6.20

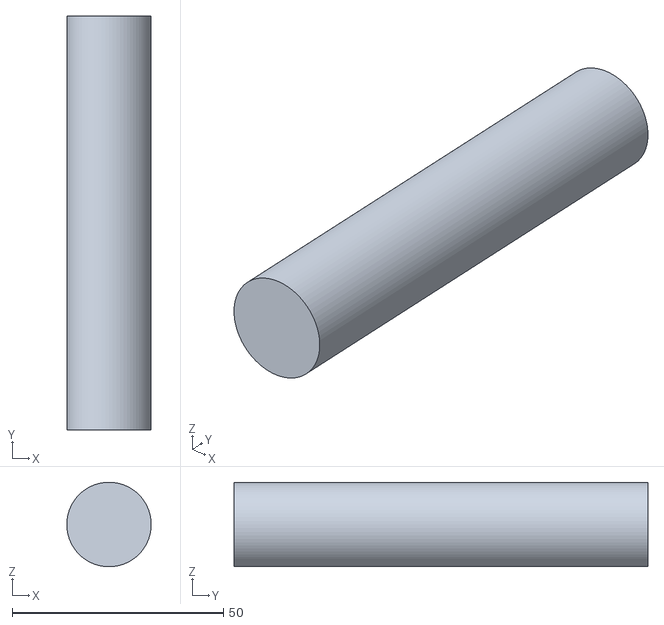
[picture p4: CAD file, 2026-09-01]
hardware/3d_models/TUBE_REFERENCE_20mm_V9.stl
20.0 x 98.0 x 20.0

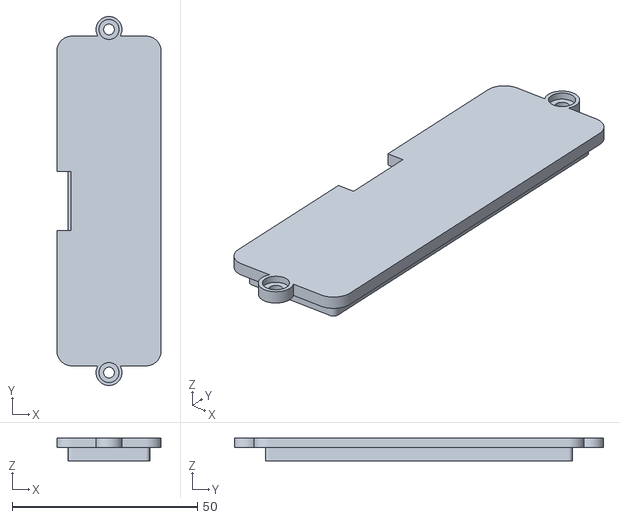
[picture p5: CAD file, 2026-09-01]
hardware/3d_models/ESP32C3_18650_Battery_Lid_V9.stl
28.2 x 99.6 x 6.20

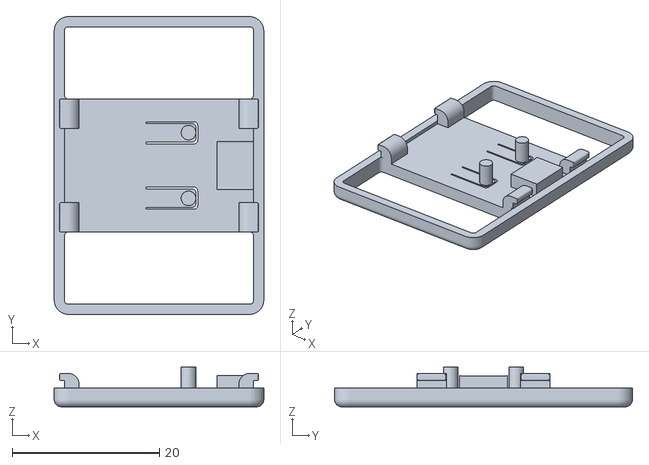
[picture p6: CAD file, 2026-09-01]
hardware/3d_models/ESP32C3_Lid_PRINT_ORIGINAL_V8.stl
28.5 x 40.5 x 5.40

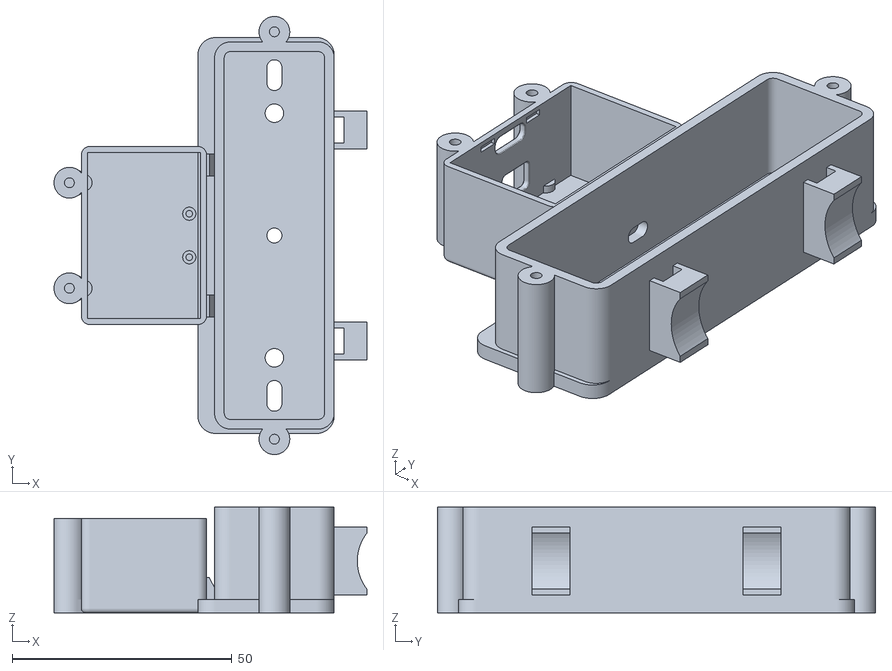
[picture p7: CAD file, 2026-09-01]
hardware/3d_models/ESP32C3_18650_Body_V9_ESP_ScrewLid.stl
71.1 x 99.6 x 24.0

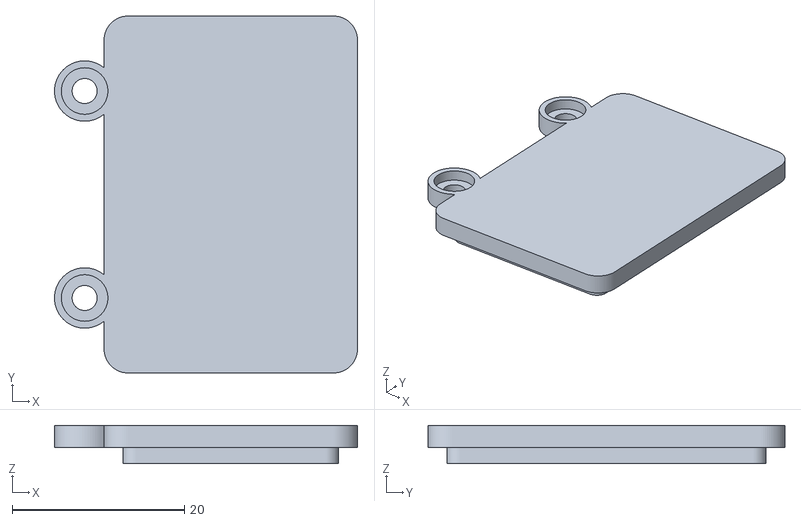
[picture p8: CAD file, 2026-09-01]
hardware/3d_models/ESP32C3_Lid_V9_2Screws.stl
35.1 x 41.4 x 4.45

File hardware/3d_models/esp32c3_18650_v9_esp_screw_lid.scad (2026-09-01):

// ESP32-C3 + closed 18650 enclosure
// V8: same as V7, plus matching wire-port hole on the ESP32 enclosure side
// so the battery cable can actually pass between the two compartments.

$fn = 72;

body_file = "/mnt/data/obj_1_Body.stl";

// Original ESP32 enclosure reference
body_xmax = 156.75;
body_y_center = 128.00;

// Battery base
plate_x0 = body_xmax - 2.0;
plate_w = 31.0;
plate_len = 90.0;
plate_y0 = body_y_center - plate_len/2;
plate_t = 3.0;
plate_r = 4.0;

// Closed battery enclosure
wall_t = 2.2;
wall_h = 21.0;
outer_x0 = body_xmax + 1.8;
outer_y0 = plate_y0 + 1.0;
outer_w = 27.2;
outer_len = plate_len - 2.0;
outer_r = 3.6;

inner_x0 = outer_x0 + wall_t;
inner_y0 = outer_y0 + wall_t;
inner_w = outer_w - 2*wall_t;
inner_len = outer_len - 2*wall_t;
inner_r = max(0.8, outer_r-wall_t);

holder_x_center = inner_x0 + inner_w/2;
outer_mount_spacing = 72.9;
terminal_spacing = 55.6;
mount_slot_len = 7.0;
mount_slot_w = 3.4;
terminal_clearance_d = 4.2;
center_hole_d = 3.4;

// Battery lid
lid_t = 2.6;
lid_lip_h = 3.8;
lid_lip_t = 1.25;
lid_clear = 0.40;
lid_overhang = 0.5;

// Lid screws on the ends
boss_d = 7.0;
boss_r = boss_d/2;
boss_x = holder_x_center;
boss_y1 = outer_y0 - boss_r + 1.2;
boss_y2 = outer_y0 + outer_len + boss_r - 1.2;
boss_top_z = plate_t + wall_h;
boss_pilot_d = 2.25;
lid_screw_clear_d = 2.9;
lid_head_d = 5.4;
lid_head_depth = 1.4;

// Wire port between compartments.
wire_port_len = 6.0;
wire_port_d = 3.2;
wire_port_z = plate_t + 5.5;
// Cut distance through the original ESP body side wall.
esp_wire_cut_len = 4.2;
// Cut distance through the battery-box ESP-facing wall.
bat_wire_cut_len = wall_t + 1.0;

// Zip-tie mounts for 20 mm tube.
tie_y1 = body_y_center - 24.0;
tie_y2 = body_y_center + 24.0;
tie_mount_w_y = 8.6;
tie_web_t_y = 1.35;
tie_gap_x = 2.25;
outer_bar_t_x = 5.2;
tie_z0 = 4.0;
tie_h = 15.5;
wall_outer_x = outer_x0 + outer_w;
bar_x0 = wall_outer_x + tie_gap_x;

tube_d = 20.0;
saddle_d = 20.8;
tube_center_x = 201.4;
tube_center_z = tie_z0 + tie_h/2;
tube_ref_len = outer_len + 10.0;

module rounded_rect_2d(w,l,r){
    hull(){
        for (x=[r,w-r])
            for (y=[r,l-r])
                translate([x,y]) circle(r=r);
    }
}

module rounded_rect_prism(x0,y0,w,l,r,h){
    translate([x0,y0,0])
        linear_extrude(height=h)
            rounded_rect_2d(w,l,r);
}

module y_slot(xc,yc,total_len,width,h){
    rr = width/2;
    sep = max(0.01,total_len-width);
    hull(){
        translate([xc,yc-sep/2,-0.5]) cylinder(r=rr,h=h+0.5);
        translate([xc,yc+sep/2,-0.5]) cylinder(r=rr,h=h+0.5);
    }
}

module support_rib(yc){
    hull(){
        translate([body_xmax-1.0,yc-2.5,2.2]) cube([1.6,5.0,5.8]);
        translate([body_xmax+2.0,yc-2.5,2.2]) cube([1.0,5.0,1.2]);
    }
}

module wire_port_cut(x_start, x_len){
    hull(){
        for (yy=[body_y_center-(wire_port_len-wire_port_d)/2,
                 body_y_center+(wire_port_len-wire_port_d)/2])
            translate([x_start,yy,wire_port_z])
                rotate([0,90,0])
                    cylinder(d=wire_port_d,h=x_len);
    }
}

module battery_box_walls(){
    difference(){
        translate([outer_x0,outer_y0,plate_t])
            linear_extrude(height=wall_h)
                rounded_rect_2d(outer_w,outer_len,outer_r);

        translate([inner_x0,inner_y0,plate_t-0.1])
            linear_extrude(height=wall_h+0.3)
                rounded_rect_2d(inner_w,inner_len,inner_r);

        // Wire port through the ESP-facing wall of the battery box.
        wire_port_cut(outer_x0-0.5, bat_wire_cut_len);
    }
}

module external_end_lid_boss(yc){
    difference(){
        translate([boss_x,yc,0]) cylinder(d=boss_d,h=boss_top_z);
        translate([boss_x,yc,2.0]) cylinder(d=boss_pilot_d,h=boss_top_z-1.5);
    }
}

module end_boss_floor_bridge(yc, direction){
    hull(){
        translate([boss_x,yc,0]) cylinder(d=boss_d,h=plate_t);
        translate([boss_x,yc + direction*3.0,0]) cylinder(d=4.0,h=plate_t);
    }
}

module zip_tie_mount(yc){
    difference(){
        union(){
            translate([bar_x0, yc-tie_mount_w_y/2, tie_z0])
                cube([outer_bar_t_x,tie_mount_w_y,tie_h]);

            translate([wall_outer_x-0.3, yc-tie_mount_w_y/2, tie_z0])
                cube([tie_gap_x+outer_bar_t_x+0.3,tie_web_t_y,tie_h]);
            translate([wall_outer_x-0.3, yc+tie_mount_w_y/2-tie_web_t_y, tie_z0])
                cube([tie_gap_x+outer_bar_t_x+0.3,tie_web_t_y,tie_h]);
        }

        translate([tube_center_x, yc-tie_mount_w_y/2-0.5, tube_center_z])
            rotate([-90,0,0]) cylinder(d=saddle_d,h=tie_mount_w_y+1.0);
    }
}

module integrated_body(){
    difference(){
        union(){
            import(body_file,convexity=10);
            rounded_rect_prism(plate_x0,plate_y0,plate_w,plate_len,plate_r,plate_t);
            support_rib(body_y_center-16.0);
            support_rib(body_y_center+16.0);
            battery_box_walls();

            end_boss_floor_bridge(boss_y1,+1);
            end_boss_floor_bridge(boss_y2,-1);
            external_end_lid_boss(boss_y1);
            external_end_lid_boss(boss_y2);

            zip_tie_mount(tie_y1);
            zip_tie_mount(tie_y2);
        }

        // Holder fixing slots: floor only.
        y_slot(holder_x_center,body_y_center-outer_mount_spacing/2,
               mount_slot_len,mount_slot_w,plate_t+0.35);
        y_slot(holder_x_center,body_y_center+outer_mount_spacing/2,
               mount_slot_len,mount_slot_w,plate_t+0.35);

        // Terminal clearance: floor only.
        translate([holder_x_center,body_y_center-terminal_spacing/2,-0.5])
            cylinder(d=terminal_clearance_d,h=plate_t+0.85);
        translate([holder_x_center,body_y_center+terminal_spacing/2,-0.5])
            cylinder(d=terminal_clearance_d,h=plate_t+0.85);
        translate([holder_x_center,body_y_center,-0.5])
            cylinder(d=center_hole_d,h=plate_t+0.85);

        // NEW: matching wire port in the ESP32 enclosure side wall.
        // This aligns with the battery-box hole so the cable really passes through.
        wire_port_cut(body_xmax-esp_wire_cut_len+0.4, esp_wire_cut_len);
    }
}

module lid_end_ear(yc, direction){
    hull(){
        translate([boss_x,yc,boss_top_z]) cylinder(d=boss_d,h=lid_t);
        translate([boss_x,yc + direction*3.0,boss_top_z]) cylinder(d=4.0,h=lid_t);
    }
}

module battery_lid(){
    difference(){
        union(){
            translate([outer_x0-lid_overhang,outer_y0-lid_overhang,boss_top_z])
                linear_extrude(height=lid_t)
                    rounded_rect_2d(outer_w+2*lid_overhang,
                                    outer_len+2*lid_overhang,
                                    outer_r+lid_overhang);

            translate([inner_x0+lid_clear,inner_y0+lid_clear,boss_top_z-lid_lip_h+0.2])
                difference(){
                    linear_extrude(height=lid_lip_h)
                        rounded_rect_2d(inner_w-2*lid_clear,
                                        inner_len-2*lid_clear,
                                        max(0.8,inner_r-lid_clear));
                    translate([lid_lip_t,lid_lip_t,-0.1])
                        linear_extrude(height=lid_lip_h+0.2)
                            rounded_rect_2d(inner_w-2*lid_clear-2*lid_lip_t,
                                            inner_len-2*lid_clear-2*lid_lip_t,
                                            max(0.6,inner_r-lid_clear-lid_lip_t));
                }

            lid_end_ear(boss_y1,+1);
            lid_end_ear(boss_y2,-1);
        }

        translate([outer_x0-lid_overhang-0.2,body_y_center-8,boss_top_z-0.2])
            cube([4.0,16.0,lid_t+1.0]);

        for (yy=[boss_y1,boss_y2]) {
            translate([boss_x,yy,boss_top_z-0.2])
                cylinder(d=lid_screw_clear_d,h=lid_t+0.5);
            translate([boss_x,yy,boss_top_z+lid_t-lid_head_depth])
                cylinder(d=lid_head_d,h=lid_head_depth+0.25);
        }
    }
}

module tube_reference(){
    color([0.55,0.55,0.55,0.35])
    translate([tube_center_x, outer_y0-5.0, tube_center_z])
        rotate([-90,0,0]) cylinder(d=tube_d,h=tube_ref_len);
}



// ---------- V9 additions: screw-on ESP lid ----------
part = "assembly"; // [body,esp_lid,battery_lid,assembly,tube_reference]

esp_x0 = 128.25;
esp_x1 = 156.75;
esp_y0 = 107.75;
esp_y1 = 148.25;
esp_w = esp_x1-esp_x0;
esp_l = esp_y1-esp_y0;
esp_cx = (esp_x0+esp_x1)/2;
esp_cy = (esp_y0+esp_y1)/2;
esp_top_z = 21.45;

esp_lid_t = 2.6;
esp_lid_overhang = 0.45;
esp_lid_r = 2.8;

// Conservative shallow locating ring inside the original opening.
esp_lip_w = 25.0;
esp_lip_l = 37.0;
esp_lip_t = 1.15;
esp_lip_h = 2.0;
esp_lip_x0 = esp_cx - esp_lip_w/2;
esp_lip_y0 = esp_cy - esp_lip_l/2;
esp_lip_r = 1.5;
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

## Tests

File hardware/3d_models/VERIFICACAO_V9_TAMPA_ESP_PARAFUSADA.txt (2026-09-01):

V9 - TAMPA DO ESP32 COM 2 PARAFUSOS

Objetivo:
Substituir a tampa original de encaixe do compartimento ESP32 por uma tampa removivel
no mesmo conceito da tampa da bateria 18650, usando dois parafusos.

Alteracoes realizadas:
- Mantida toda a geometria funcional da V8:
  * caixa 18650 fechada;
  * tampa 18650 com 2 parafusos;
  * furos do holder 18650;
  * passa-cabo alinhado entre bateria e ESP32;
  * dois suportes para presilhas do tubo de ~20 mm.
- Adicionados 2 postes externos para a tampa do ESP32.
- Postes posicionados no lado do ESP32 oposto a bateria, evitando os conectores das faces frontal/traseira.
- Nova tampa ESP32 plana, com borda interna rasa de posicionamento e 2 orelhas de parafuso.

Parafusos sugeridos para a tampa ESP32:
- 2x M2.5 x 8 mm para plastico / autoatarraxante.
- Furo piloto do poste: 2.25 mm.
- Furo passante da tampa: 2.9 mm.
- Rebaixo de cabeca: 5.4 mm.

Posicao dos parafusos ESP32:
- X = 125.55 mm
- Y = 116.00 mm e 140.00 mm
- Separacao entre centros = 24.00 mm

Verificacao de encaixe:
- Foi feita intersecao CAD entre corpo e nova tampa na posicao fechada.
- A intersecao volumetrica foi 0 mm3; existe apenas contato no plano de apoio Z=21.45 mm.
- Portanto a borda interna da nova tampa nao invade as paredes do corpo.

Arquivos:
- ESP32C3_18650_Body_V9_ESP_ScrewLid.stl
- ESP32C3_Lid_V9_2Screws.stl
- ESP32C3_18650_Battery_Lid_V9.stl
- TUBE_REFERENCE_20mm_V9.stl
- esp32c3_18650_v9_esp_screw_lid.scad

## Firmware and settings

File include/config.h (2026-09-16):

#pragma once

#include <stdint.h>
#include <stddef.h>

// =============================================================================
// HARDWARE PIN DEFINITIONS (ESP32-C3)
// =============================================================================
#ifndef PIN_SENSOR
#define PIN_SENSOR          21  // GPIO 21: P2 Jack tip (Sensor input, interrupt + wakeup)
#endif

#ifndef PIN_BATTERY_ADC
#define PIN_BATTERY_ADC     0   // GPIO 0: ADC1_CH0 (100k/100k voltage divider to 18650)
#endif

#ifndef PIN_BTN_SETUP
#define PIN_BTN_SETUP       9   // GPIO 9: Native BOOT button (Active LOW, hold for Wi-Fi Setup)
#endif

#ifndef PIN_LED_STATUS
#define PIN_LED_STATUS      8   // GPIO 8: Status LED (Active LOW on most C3 modules)
#endif

#ifndef ERGOBIKE_FTMS_ONLY
#define ERGOBIKE_FTMS_ONLY  0   // Set to 1 for MyWhoosh compatibility testing
#endif

// =============================================================================
// DEFAULT FACTORY PARAMETERS
// =============================================================================
#define DEFAULT_DEVICE_NAME         "ErgoBike-BLE"
#define DEFAULT_WHEEL_CIRC_MM       5000      // Effective distance per sensor pulse (5 m per pedal revolution)
#define DEFAULT_GEAR_RATIO          1.00f     // Bike sensor gives 1 pulse per crank (pedal) revolution
#define DEFAULT_DEBOUNCE_MS         15        // Sensor software debounce filter (milliseconds)
#define DEFAULT_INACTIVITY_SLEEP_SEC 180      // 3 minutes before auto Deep Sleep
#define DEFAULT_STOP_TIMEOUT_MS     2200      // Stop detection: 2.2 seconds with no pulse => 0 RPM / 0 km/h
#define DEFAULT_ADC_CAL_FACTOR      2.00f     // 100k/100k divider multiplier

#define AP_SSID                     "ErgoBike-Setup"
#define AP_PASS                     "12345678"
#define AP_IP_STR                   "192.168.4.1"

// =============================================================================
// BLE SERVICE & CHARACTERISTIC UUIDS (Bluetooth SIG Standard)
// =============================================================================
// Cycling Speed and Cadence Service (CSCS)
#define UUID_SERVICE_CSC            "1816"
#define UUID_CHAR_CSC_MEASUREMENT   "2A5B"
#define UUID_CHAR_CSC_FEATURE       "2A5C"
#define UUID_CHAR_SENSOR_LOCATION   "2A5D"
#define UUID_CHAR_CSC_CONTROL_POINT "2A55"
#define CSC_APPEARANCE              0x0485  // Cycling: Speed and Cadence Sensor
#define CSC_SENSOR_LOCATION         0x05    // Left Crank

// Fitness Machine Service (FTMS)
#define UUID_SERVICE_FTMS           "1826"
#define UUID_CHAR_INDOOR_BIKE_DATA  "2AD2"
#define UUID_CHAR_FTMS_FEATURE      "2ACC"
#define UUID_CHAR_FTMS_CONTROL_POINT "2AD9"
#define UUID_CHAR_FTMS_STATUS       "2ADA"

// Battery Service (BAS)
#define UUID_SERVICE_BATTERY        "180F"
#define UUID_CHAR_BATTERY_LEVEL     "2A19"

// Device Information Service (DIS)
#define UUID_SERVICE_DEVICE_INFO    "180A"
#define UUID_CHAR_MANUFACTURER      "2A29"
#define UUID_CHAR_MODEL_NUMBER      "2A24"
#define UUID_CHAR_FIRMWARE_REV      "2A26"

// =============================================================================
// SYSTEM CONFIGURATION STRUCT (Stored in NVS)
// =============================================================================
struct BikeConfig {
    char deviceName[32];
    uint16_t wheelCircMm;       // Effective distance per sensor pulse, in millimeters
    float gearRatio;            // Flywheel revolutions per 1 pedal crank turn
    uint16_t debounceMs;        // Debounce window in ms
    uint16_t inactivitySleepSec;// Timeout before deep sleep
    float adcMultiplier;        // Calibration factor for voltage divider
    uint16_t nvsVersion;        // Data structure schema version
};

// =============================================================================
// RUNTIME METRICS STRUCT
// =============================================================================
struct BikeMetrics {
    float speedKmh;             // Virtual speed in km/h
    float cadenceRpm;           // Pedal cadence in RPM
    uint32_t totalPulses;       // Total pulses counted
    uint32_t cumulativeWheelRevs;
    uint16_t lastWheelEventTime1024; // 1/1024 s resolution
    uint16_t cumulativeCrankRevs;
    uint16_t lastCrankEventTime1024; // 1/1024 s resolution
    float batteryVoltage;       // Battery Volts
    uint8_t batteryPercentage;  // Battery 0-100%
    bool isConnected;           // BLE client connected
    bool isPedaling;            // Currently moving
};

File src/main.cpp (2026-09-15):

#include <Arduino.h>
#include <esp_timer.h>

#include "config.h"
#include "sensor_reader.h"
#include "battery_monitor.h"
#include "storage_manager.h"
#include "ble_manager.h"
#include "power_manager.h"
#include "web_portal.h"

// System instances
static StorageManager s_storage;
static SensorReader   s_sensor;
static BatteryMonitor s_battery;
static BLEManager     s_ble;
static PowerManager   s_power;
static WebPortal      s_portal;

// Runtime state
static bool s_isConfigMode = false;
static uint32_t s_lastLedToggleMs = 0;
static bool s_ledState = false;
static uint32_t s_lastSerialLogMs = 0;
static uint32_t s_pulseFlashUntilMs = 0;

// Hardware Interrupt for Sensor Pulses
void IRAM_ATTR isr_sensor_trigger() {
    uint64_t now_us = esp_timer_get_time();
    s_sensor.onPulse(now_us);
    s_pulseFlashUntilMs = millis() + 40;
}

// Check if BOOT button is held at power-on to enter Wi-Fi Setup Mode
bool checkSetupButtonHeld() {
    pinMode(PIN_BTN_SETUP, INPUT_PULLUP);
    if (digitalRead(PIN_BTN_SETUP) == LOW) {
        Serial.println("[BOOT] Setup button pressed. Checking hold duration...");
        uint32_t startMs = millis();
        while (digitalRead(PIN_BTN_SETUP) == LOW) {
            if (millis() - startMs > 2000) {
                return true; // Held for > 2 seconds
            }
            delay(10);
        }
    }
    return false;
}

void setup() {
    Serial.begin(115200);
    delay(500);

    Serial.println("\n=========================================");
    Serial.println("   ErgoBike BLE Smart Trainer (ESP32-C3)  ");
    Serial.println("=========================================");

    // Initialize LED
    pinMode(PIN_LED_STATUS, OUTPUT);
    digitalWrite(PIN_LED_STATUS, HIGH); // Off initially (Active-LOW)

    // Load configuration from NVS
    s_storage.begin();
    BikeConfig config = s_storage.getConfig();

    Serial.printf("[CONFIG] Device Name: %s\n", config.deviceName);
    Serial.printf("[CONFIG] Wheel Circ:  %u mm\n", config.wheelCircMm);
    Serial.printf("[CONFIG] Gear Ratio:  %.2f:1\n", config.gearRatio);
    Serial.printf("[CONFIG] Debounce:    %u ms\n", config.debounceMs);
    Serial.printf("[CONFIG] Sleep Time:  %u sec\n", config.inactivitySleepSec);

    // Initialize Core Modules
    s_sensor.begin(config);
    s_battery.begin(config);

    // Initialize Button & Sensor Pins
    pinMode(PIN_BTN_SETUP, INPUT_PULLUP);
    pinMode(PIN_SENSOR, INPUT_PULLUP);

    s_power.begin(config);

    attachInterrupt(digitalPinToInterrupt(PIN_SENSOR), isr_sensor_trigger, FALLING);

    // Check if user requested Wi-Fi Setup Portal at boot
    s_isConfigMode = checkSetupButtonHeld();

    if (s_isConfigMode) {
        Serial.println("[MODE] >>> INICIANDO MODO WI-FI / PORTAL DE CONFIGURAÇÃO <<<");
        s_portal.begin(&s_storage, &s_sensor, &s_battery);
    } else {
        Serial.println("[MODE] >>> INICIANDO MODO NORMAL / BLUETOOTH LOW ENERGY <<<");
        s_ble.begin(config.deviceName);
#if ERGOBIKE_FTMS_ONLY
        Serial.println("[BLE] Anunciando FTMS (0x1826) + Bateria (0x180F)...");
#else
        Serial.println("[BLE] Anunciando CSCS (0x1816) + FTMS (0x1826) + Bateria (0x180F)...");
#endif
        Serial.println("[BLE] Pronto para conectar com CycleGo, Zwift e outros apps!");
    }
}

void handleLedFeedback() {
    uint32_t now = millis();

    // Flash LED on active pulse
    if (now < s_pulseFlashUntilMs) {
        digitalWrite(PIN_LED_STATUS, LOW); // ON
        return;
    }

    if (s_isConfigMode) {
        // Wi-Fi Config Mode: Fast blink (100ms on / 100ms off)
        if (now - s_lastLedToggleMs >= 100) {
            s_lastLedToggleMs = now;
            s_ledState = !s_ledState;
            digitalWrite(PIN_LED_STATUS, s_ledState ? LOW : HIGH);
        }
    } else {
        if (s_ble.isConnected()) {
            // Connected to App: Solid ON
            digitalWrite(PIN_LED_STATUS, LOW);
        } else {
            // Disconnected / Advertising: Slow pulse every 2s (100ms flash)
            uint32_t cycle = now % 2000;
            digitalWrite(PIN_LED_STATUS, (cycle < 100) ? LOW : HIGH);
        }
    }
}

void loop() {
    uint64_t now_us = esp_timer_get_time();
    uint32_t now_ms = millis();

    // 1. Process Sensor timeouts
    s_sensor.update(now_us);

    // 2. Process LED status
    handleLedFeedback();

    if (s_isConfigMode) {
        // Run Wi-Fi Portal
        s_portal.update();
        s_battery.update();
    } else {
        // Monitor setup button during runtime (hold 2s to switch to config mode)
        static uint32_t s_btnPressStartMs = 0;
        if (digitalRead(PIN_BTN_SETUP) == LOW) {
            if (s_btnPressStartMs == 0) {
                s_btnPressStartMs = now_ms;
            } else if (now_ms - s_btnPressStartMs >= 2000) {
                Serial.println("[BOOT] Setup button held for 2s. Switching to Wi-Fi Setup Mode...");
                s_ble.stop();
                s_isConfigMode = true;
                s_portal.begin(&s_storage, &s_sensor, &s_battery);
                s_btnPressStartMs = 0;
            }
        } else {
            s_btnPressStartMs = 0;
        }

        // Run BLE Normal Mode
        s_battery.update();
        s_ble.update(s_sensor, s_battery);
        s_power.update(s_sensor.isPedaling(), s_ble.isConnected());

        // Periodic Serial Monitor output
        if (now_ms - s_lastSerialLogMs >= 1000) {
            s_lastSerialLogMs = now_ms;
            Serial.printf("[TRAINER] Cad: %5.1f RPM | Spd: %5.1f km/h | Pulses: %6u | Bat: %3u%% (%.2fV) | BLE: %s | SleepIn: %us\n",
                s_sensor.getCadenceRpm(),
                s_sensor.getSpeedKmh(),
                s_sensor.getTotalPulses(),
                s_battery.getPercentage(),
                s_battery.getVoltage(),
                s_ble.isConnected() ? "CONNECTED" : "ADVERTISING",
                s_power.getSecondsUntilSleep()
            );
        }
    }

    delay(5);
}

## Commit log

2026-09-01 docs: add technical design spec for ergobike ble sensor
2026-09-01 docs: add comprehensive implementation plan for ergobike ble sensor
2026-09-01 chore: setup platformio config, partition table, and config header
    [min_spiffs.csv]
2026-09-01 feat: implement sensor reader engine and algorithm unit tests
2026-09-01 feat: implement battery monitor and discharge curve tests
2026-09-01 feat: implement dual ble stack cscs ftms and battery service
2026-09-01 feat: implement power manager with gpio wake deep sleep
2026-09-01 feat: implement wifi setup portal live dashboard calibration wizard and ota
2026-09-01 feat(hardware): add 3d printable enclosure v9 cad files and stl models
    [ESP32C3_18650_Battery_Lid_V9.stl, ESP32C3_18650_Body_V9_ESP_ScrewLid.stl, ESP32C3_Lid_PRINT_ORIGINAL_V8.stl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]
2026-09-01 docs: enrich readme with badges, 3d enclosure previews, app compatibility matrix, and hardware guide
2026-09-01 feat(hardware): add battery lid split stl variant
    [ESP32C3_18650_Battery_Lid_V9-split-2-split-1-split-2.stl]
2026-09-07 fix: resolve build issues, sensor speed math, sleep wakeups, and add expansion board support
    [battery_monitor.cpp, config.h, main.cpp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]
2026-09-13 fix: advertise instantaneous cadence in FTMS data
    [ble_manager.cpp]
2026-09-13 fix: initialize GPIO21 wakeup before sensor interrupt
    [main.cpp, power_manager.cpp]
2026-09-15 fix: restore FTMS instantaneous cadence flag 0x0004
    [ble_manager.cpp]
2026-09-15 fix: round FTMS speed and cadence units
    [ble_manager.cpp]
2026-09-15 feat: calibrate virtual circumference to match bike computer speed
2026-09-15 fix: default gear ratio 1.0 for single-pulse crank sensor
    [config.h, storage_manager.cpp]
2026-09-15 feat: add FTMS power and wheel calibration

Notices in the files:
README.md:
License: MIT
